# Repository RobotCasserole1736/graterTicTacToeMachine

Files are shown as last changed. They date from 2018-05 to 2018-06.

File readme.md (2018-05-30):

# Tic Tac Toe

This is code for our machine which plays tic tac toe.

It is cheesey. But also grate. Hopefully the kids will love it.

# Gameplay

To begin, the human draws a red X on their board. They place the board into the machine, then press the "Play" button.

The robot analyzes the board state, chooses where to place an O, and draws it. The human takes the board and draws another X. 

The process repeats until one player has won the game.

# Algorithm

A medium-difficulty algorithm has been implemented:
 - If the robot (O's) can win with a single move, the robot will make that move
 - If the human (X's) can win with a single move, the robot will block that move
 - Otherwise, the robot will place in a random location.

# Structure

## JeVois Vision Camera

 - Takes images of the board to determine which spaces are populated by the robot or the human
 - Recieves command from the Arduino to process the present image
 - Transmits board state to the Arduino
 
 ## Arduino
 
  - Mega 
  - Maintains state machine for full robot state
  - On Play button press, sends command to JeVois to read board state
  - Listens for and Parses JeVois response
  - Calculates mark placement location
  - Plans stepper motor paths to draw the mark 
  - Sends commands to stepper motor driver to execute draw
  
  ## Physical Motor
   
   - 3 axis pen moving rig
   
  # Credits
  
  Some days you eat the cheese, some days the cheese eats you.

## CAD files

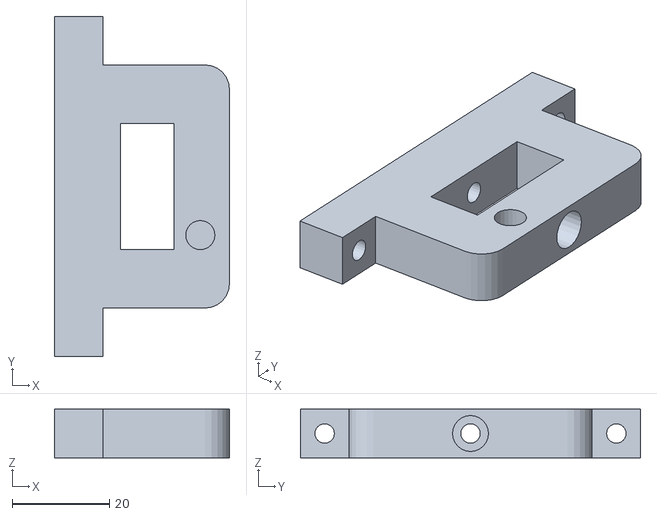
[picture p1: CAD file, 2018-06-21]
3D_Parts/StepperFot.stl
36.0 x 70.0 x 10.0

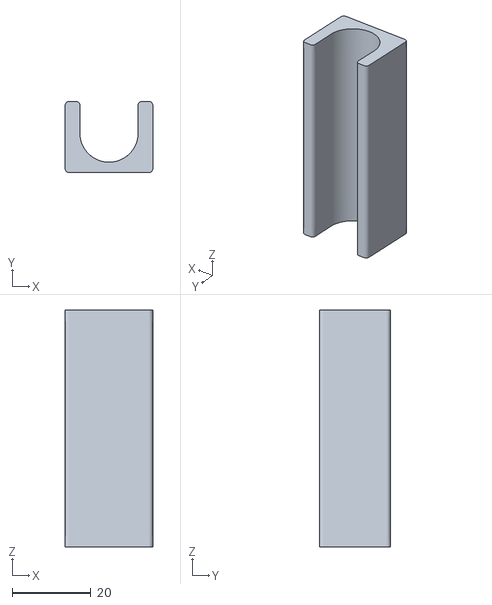
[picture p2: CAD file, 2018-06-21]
3D_Parts/NutStabilizer.stl
22.2 x 18.0 x 60.0

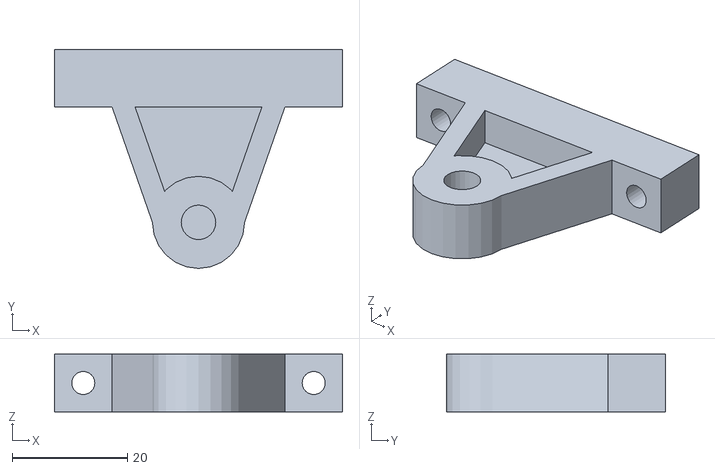
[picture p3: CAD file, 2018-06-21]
3D_Parts/Fot.stl
50.0 x 38.0 x 10.0

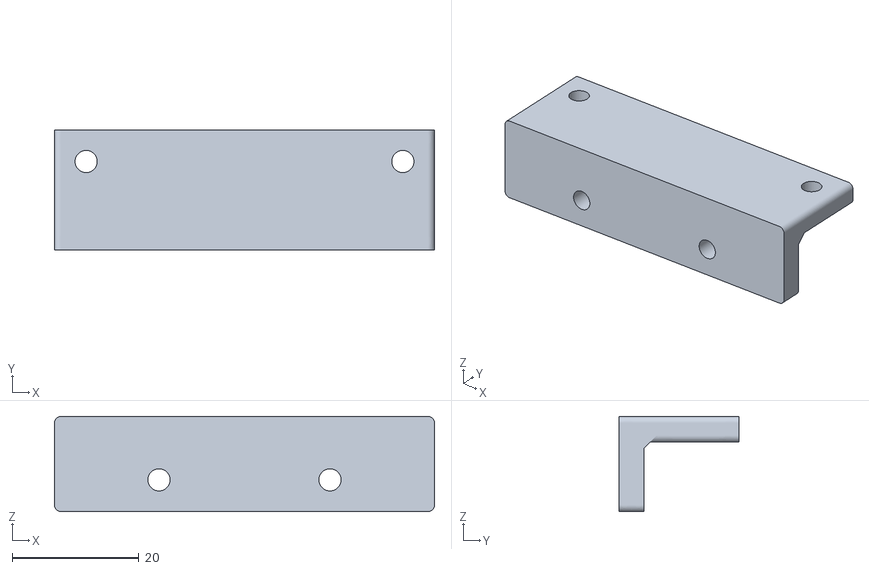
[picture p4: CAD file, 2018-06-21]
3D_Parts/PenStepperMount.stl
60.0 x 19.0 x 15.0

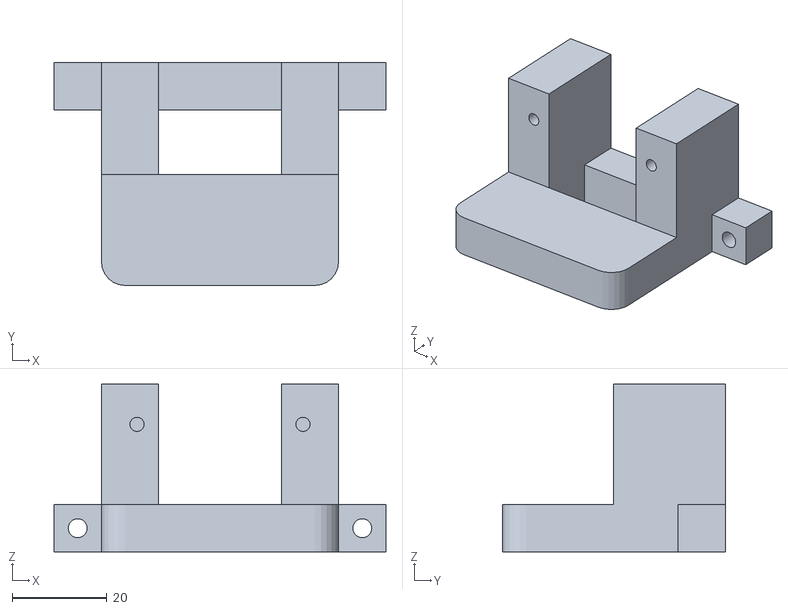
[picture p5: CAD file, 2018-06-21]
3D_Parts/StepperMountY.stl
70.0 x 47.0 x 35.4

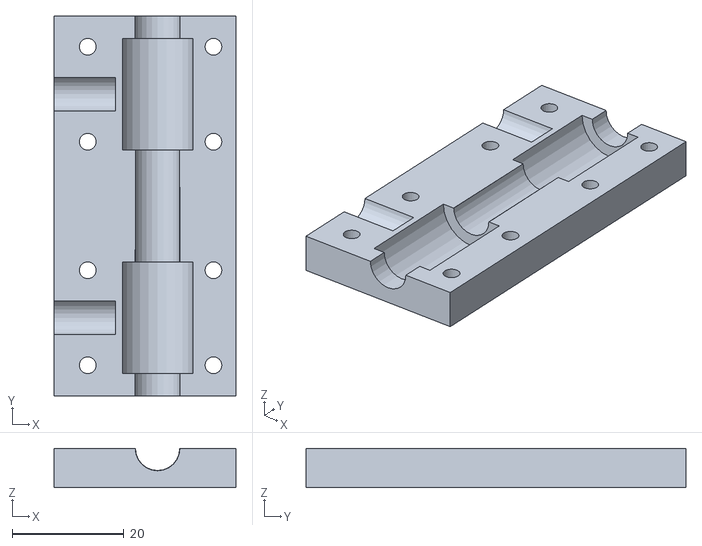
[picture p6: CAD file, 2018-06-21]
3D_Parts/Klammer.stl
32.5 x 68.0 x 7.00

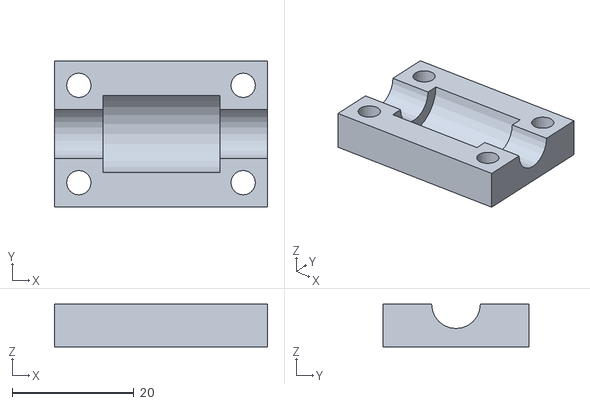
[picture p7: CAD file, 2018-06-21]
3D_Parts/XbaseTop.stl
35.0 x 24.0 x 7.00

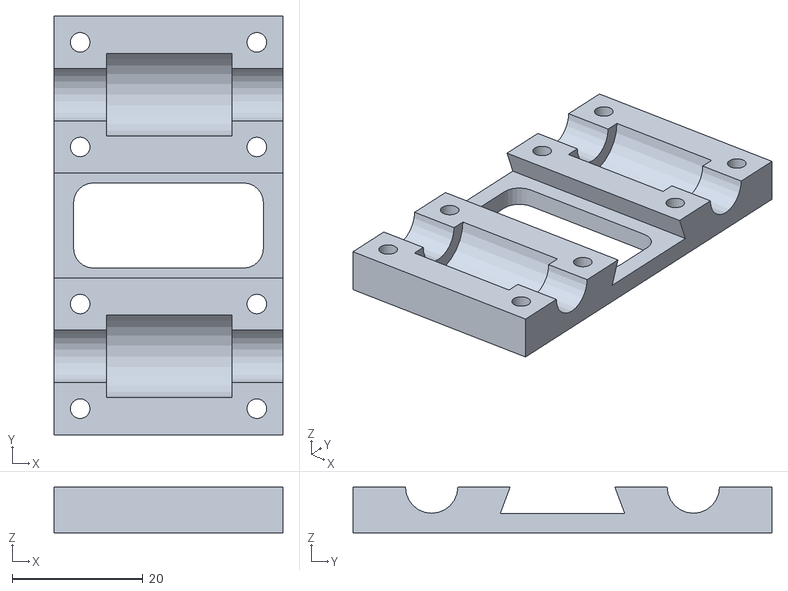
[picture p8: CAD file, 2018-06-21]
3D_Parts/Xbase.stl
35.0 x 64.0 x 7.00

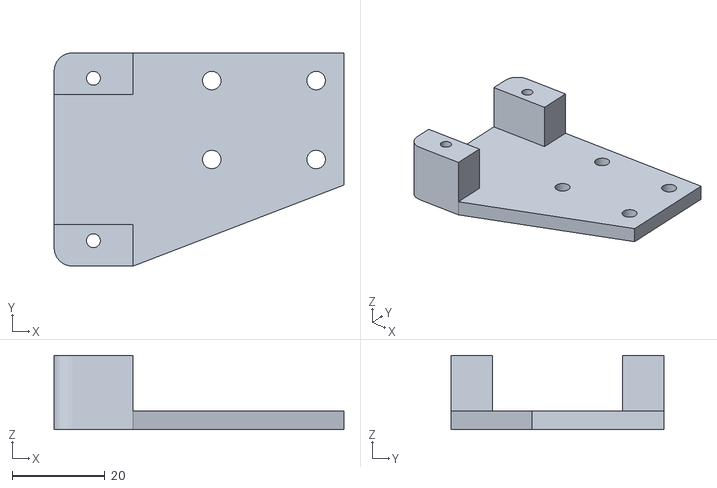
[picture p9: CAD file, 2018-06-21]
3D_Parts/StepperMountX.stl
62.5 x 46.0 x 16.0

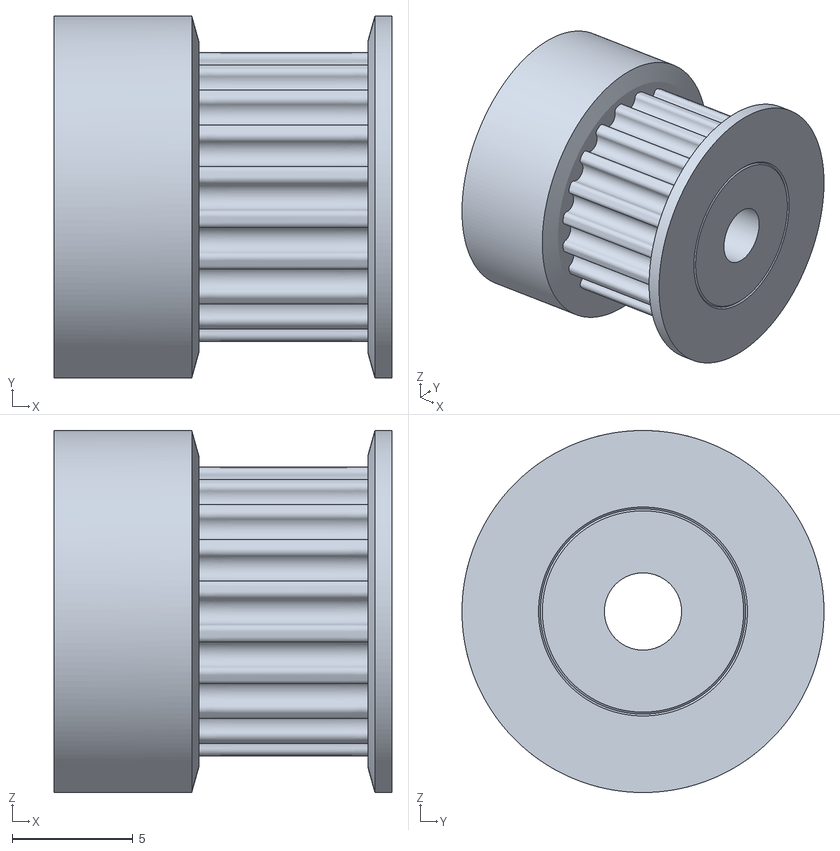
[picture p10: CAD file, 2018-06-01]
3D_Parts/Pulley_GT2.stl
14.0 x 15.0 x 15.0

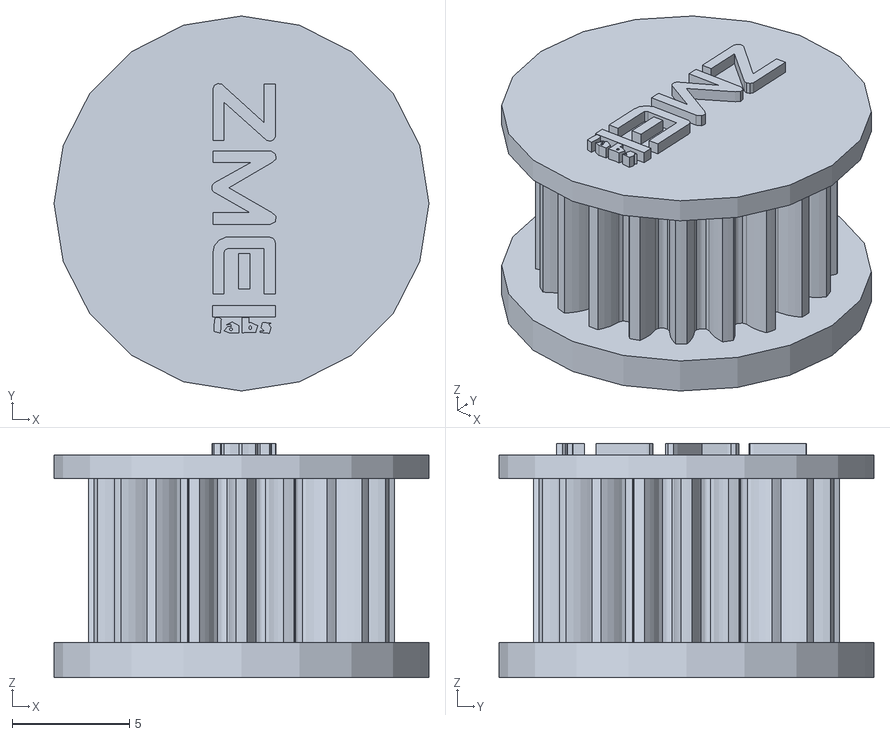
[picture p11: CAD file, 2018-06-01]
3D_Parts/Gears_For_GT02_Arduino.stl
16.0 x 16.0 x 10.0

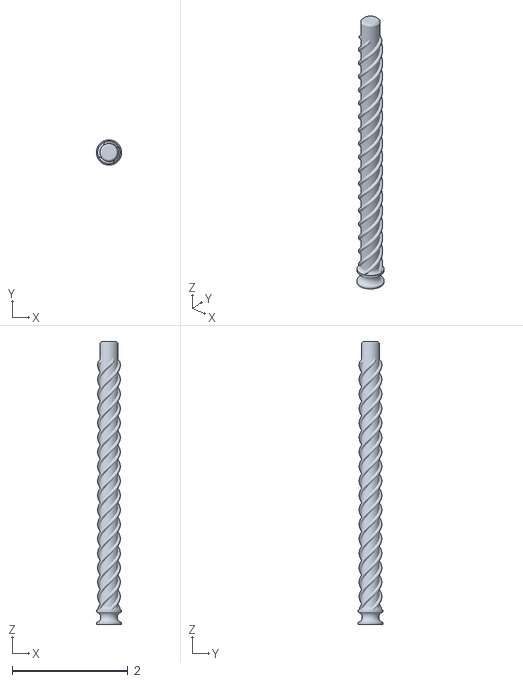
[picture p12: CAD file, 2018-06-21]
3D_Parts/BS-V1-SCREW-1-QUAD.stl
0.437 x 0.437 x 4.89

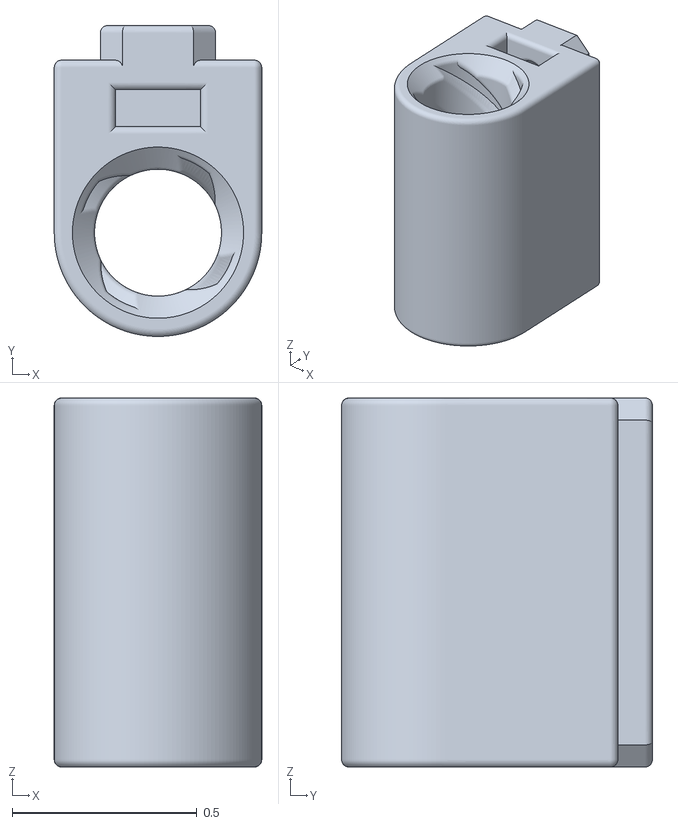
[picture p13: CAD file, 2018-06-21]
3D_Parts/BS-V1-NUT-1.stl
0.563 x 0.843 x 1.00

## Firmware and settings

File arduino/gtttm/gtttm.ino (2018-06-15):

#include "AccelStepper.h"

/*
 * The Grater Tic Tac Toe Machine
 * Plays tic tac toe and such.
 * It's Cheesy and Grate. mmmmmm
 * 
 *          _--"-.
      .-"      "-.
     |""--..      '-.
     |      ""--..   '-.
     |.-. .-".    ""--..".
     |'./  -_'  .-.      |
     |      .-. '.-'   .-'
     '--..  '.'    .-  -.
          ""--..   '_'   :
                ""--..   |
                      ""-' 
 * 
 * Serial
 * See License.txt in the root of the repo!
 */

////////////////////////////////////////////////////////////
// Debug print switches
////////////////////////////////////////////////////////////
//Uncomment this to get a bunch more spammed to the debug serial port
//#define DEBUG_POS


////////////////////////////////////////////////////////////
// Constant Values
////////////////////////////////////////////////////////////

//Physical hardware IO def's
#define X_STEPPER_PIN_1 3
#define X_STEPPER_PIN_2 4
#define X_STEPPER_PIN_3 5
#define X_STEPPER_PIN_4 6

#define Y_STEPPER_PIN_1 7
#define Y_STEPPER_PIN_2 8
#define Y_STEPPER_PIN_3 9
#define Y_STEPPER_PIN_4 10

#define Z_STEPPER_PIN_1 11
#define Z_STEPPER_PIN_2 12
#define Z_STEPPER_PIN_3 16
#define Z_STEPPER_PIN_4 14

//Stepper Operational mode defs
#define HALFSTEP 8

//Jevois interaface
#define JEVOIS_BOARD_STATE_REQ_STR "GRATERTTT\n"
#define JEVOIS_READ_TIMEOUT_MS 10000

//Other IO
#define PLAY_BUTTON_PIN 15
#define PLAY_BUTTON_DBNC_LOOPS 10 //Count to debounce the play button switch for
#define PLAY_BUTTON_PRESSED true //state that digitalRead should return when pressed
#define BUILT_IN_LED_PIN 13


//Motor Motion Constants.
// With the exception of steps/mm, all distances in mm
#define STEPS_PER_MM 60
#define GRID_X_OFFSET 50.0
#define GRID_Y_OFFSET 50.0

#define PEN_UP_POS 0.0
#define PEN_DOWN_POS -50.0
#define CELL_X_SIZE 10.0
#define CELL_Y_SIZE 10.0

#define DRAWN_CIRCLE_RADIUS CELL_X_SIZE/3.0
#define DRAWN_CIRCLE_APROX_STEPS 16 //Number of steps to use to approximate a circle with straight lines

#define MAX_SPEED_MM_PER_SEC 12
#define MAX_ACCEL_MM_PER_SEC2 100

//#define MAX_SPEED_MM_PER_SEC 5000
//#define MAX_ACCEL_MM_PER_SEC2 5000



//Operation states
enum opState_t{
  WAIT_FOR_USER,        //waiting for the user to hit the button to request a move
  REQ_BOARD_STATE,      //Request the board state from the Jevois
  WAIT_FOR_BOARD_STATE, //Wait for the Jevois to return the board state
  CALC_MOVE,            //Calculate which cell to put a mark in
  WAIT_FOR_MOVE         //Make the move,slick
};


////////////////////////////////////////////////////////////
// Global Vars
////////////////////////////////////////////////////////////

//The board is a 3x3 array of cells
// Each cell can be blank (_), have Robot mark (O), or a human mark (X)
// This will be populated by the JeVois's serial response.
//
// Board Numbering & Orientation Scheme:
//              |       |              Positive Z: Down into the paper
//          0   |   1   |   2          
//       _______|_______|_______       |
//              |       |             -+---> X
//          3   |   4   |   5          |
//       _______|_______|_______       |
//              |       |              V
//          6   |   7   |   8          y
//              |       |              
char BoardState[9];

//The present state of the arduino controller
opState_t State;

//Stepper Motor Objects
//Note pins 2/3 are flipped for reasons (????)
//The electrical hookup should match the macro definitions
AccelStepper stepperX(HALFSTEP, X_STEPPER_PIN_1, X_STEPPER_PIN_3, X_STEPPER_PIN_2, X_STEPPER_PIN_4);
AccelStepper stepperY(HALFSTEP, Y_STEPPER_PIN_1, Y_STEPPER_PIN_3, Y_STEPPER_PIN_2, Y_STEPPER_PIN_4);
AccelStepper stepperZ(HALFSTEP, Z_STEPPER_PIN_1, Z_STEPPER_PIN_3, Z_STEPPER_PIN_2, Z_STEPPER_PIN_4);

//Play button debouncing
unsigned int playButtonDbncCounter = PLAY_BUTTON_DBNC_LOOPS;



////////////////////////////////////////////////////////////
// Movement Sequencer - Circle draw algorithm
////////////////////////////////////////////////////////////
#define CELL_UNDEFINED -1
int targetCell = CELL_UNDEFINED;

//In our sequencer, we move through a sequence of steps.
// 0 = move from home to first point of circle
// 1 = Lower pen
// 2 = move first point of circle to second point of circle
// ...
// DRAWN_CIRCLE_APROX_STEPS + 2 = move to final point on circle
// DRAWN_CIRCLE_APROX_STEPS + 3 = Raise pen
// DRAWN_CIRCLE_APROX_STEPS + 4 = move home
unsigned int sequenceStep = 0;

//home->circle, lower pen, draw circle, raise pen, circle->home
#define TOTAL_STEPS  (1 + 1 + DRAWN_CIRCLE_APROX_STEPS + 1 + 1)

//True if we're moving, false if we're done moving
bool moveInProcess = false;
bool newStep = false;

//"Origin" of the target cell - top-right corner
float tgtCellXPos = 0;
float tgtCellYPos = 0;

//Center of the target cell
float tgtCellXCenter = 0;
float tgtCellYCenter = 0;

//Circle points
float circleXCoords[DRAWN_CIRCLE_APROX_STEPS+1] = {0};
float circleYCoords[DRAWN_CIRCLE_APROX_STEPS+1] = {0};

//Sets a new target cell to draw an output in
//Calculates path constants while it's at it.
void mvSeqSetTargetCell(int tgt_in){
  targetCell = tgt_in;

  //Calc the origin of the target cell
  tgtCellXPos = GRID_X_OFFSET + (CELL_X_SIZE * (float)(tgt_in % 3));
  tgtCellYPos = GRID_Y_OFFSET + (CELL_Y_SIZE * (float)(tgt_in / 3));
  
  //calc the center of the cell
  tgtCellXCenter = tgtCellXPos + CELL_X_SIZE/2.0;
  tgtCellYCenter = tgtCellYPos + CELL_Y_SIZE/2.0;

  //Calc the points on the circle
  for(int pointIdx = 0; pointIdx < DRAWN_CIRCLE_APROX_STEPS+1;  pointIdx++){
    float angleRad = ((float)(pointIdx)) / ((float)DRAWN_CIRCLE_APROX_STEPS) * 2.0 * 3.14159;
    circleXCoords[pointIdx] = tgtCellXCenter + DRAWN_CIRCLE_RADIUS * sin( angleRad );
    circleYCoords[pointIdx] = tgtCellYCenter + DRAWN_CIRCLE_RADIUS * cos( angleRad );
  }

  moveInProcess = true;
  sequenceStep = 0;
  newStep = true;

  Serial.println("Finished calculating new path.");
}


unsigned int updateCtr = 0;

void mvSeqUpdate(){
  //Circle-draw algorithm
  if(newStep == true){
     Serial.print("Running step ");
     Serial.print(sequenceStep);
     Serial.println("...");

    if(sequenceStep == 0){
      //Move to start of circle
      stepperX.moveTo(mmToSteps(circleXCoords[0]));
      stepperY.moveTo(mmToSteps(circleYCoords[0]));
      stepperZ.moveTo(mmToSteps(PEN_UP_POS));
    } else if(sequenceStep == 1){
      //Lower pen
      stepperX.moveTo(mmToSteps(circleXCoords[0]));
      stepperY.moveTo(mmToSteps(circleYCoords[0]));
      stepperZ.moveTo(mmToSteps(PEN_DOWN_POS));
    } else if(sequenceStep >= 2 && sequenceStep <= DRAWN_CIRCLE_APROX_STEPS + 2){
      //Draw circle
      stepperX.moveTo(mmToSteps(circleXCoords[sequenceStep-2]));
      stepperY.moveTo(mmToSteps(circleYCoords[sequenceStep-2]));
      stepperZ.moveTo(mmToSteps(PEN_DOWN_POS));
    } else if(sequenceStep == DRAWN_CIRCLE_APROX_STEPS + 3){
      //Raise pen
      stepperX.moveTo(mmToSteps(circleXCoords[DRAWN_CIRCLE_APROX_STEPS]));
      stepperY.moveTo(mmToSteps(circleYCoords[DRAWN_CIRCLE_APROX_STEPS]));
      stepperZ.moveTo(mmToSteps(PEN_UP_POS));
    }else if(sequenceStep == DRAWN_CIRCLE_APROX_STEPS + 4){
      //Move home
      stepperX.moveTo(mmToSteps(0));
      stepperY.moveTo(mmToSteps(0));
      stepperZ.moveTo(mmToSteps(PEN_UP_POS));
    } else {
      //IDK let's go home
      stepperX.moveTo(mmToSteps(0));
      stepperY.moveTo(mmToSteps(0));
      stepperZ.moveTo(mmToSteps(PEN_UP_POS));
    }
  }

  //If we're at 0 distance-to-go, we can move on to the next step
  if(stepperX.isRunning() == false &&
     stepperY.isRunning() == false &&
     stepperZ.isRunning() == false ) {

       sequenceStep++;
       newStep = true;
       moveInProcess = true;

       Serial.print("Finished step ");
       Serial.println(sequenceStep-1);
       if( sequenceStep > TOTAL_STEPS){
         //All done, clean up variable state
         moveInProcess = false;
         newStep = false;
         sequenceStep = 0;
       }
       
  } else {
    newStep = false;
    moveInProcess = true;
    
  #ifdef DEBUG_POS
    Serial.println("\n\n===============");
    Serial.print("POS X = ");
    Serial.println(stepperX.currentPosition());
    Serial.print("POS Y = ");
    Serial.println(stepperY.currentPosition());
    Serial.print("POS Z = ");
    Serial.println(stepperZ.currentPosition());
  #endif
  }

}

void mvSeqOutputUpdate(){
  //Do periodic output updates
  stepperX.run();
  stepperY.run();
  stepperZ.run();
}



////////////////////////////////////////////////////////////
// Utility functions
////////////////////////////////////////////////////////////
void resetState(){
  State = WAIT_FOR_USER;
  for(int cellIdx = 0; cellIdx < 9; cellIdx++){
    BoardState[cellIdx] = "_";
  }

  targetCell = CELL_UNDEFINED;
}

//Returns an index 0-8 to say where the robot should place a 
// mark. Should calculate this based on BoardState.
int moveCalculator(){
  int des_move = 0;
  int avail_cells[9] = {0};
  int num_avail_cells = 0;

  //Populate the array of available moves
  for(int cell = 0; cell < 9; cell++){
    if(BoardState[cell] == ' '){
      avail_cells[num_avail_cells++] = cell;
    }
  }

  //Check for no move available
  if(num_avail_cells == 0){
    return -1;
  }
  
  //TODO: Fill me in with logic to win against the kids, but not too hard

  //else: choose randomly
  des_move = avail_cells[random(0,num_avail_cells)];

  return des_move;

}

//converts mm to steps
float mmToSteps(float mm){
  return STEPS_PER_MM * mm;
}

void printBoardState(void){
  Serial.println("Board State:");
  Serial.println("       |     |     ");   
  Serial.print("    ");Serial.print(BoardState[0]);Serial.print("  |  ");Serial.print(BoardState[1]);Serial.print("  |  ");Serial.print(BoardState[2]);Serial.print("  \n");
  Serial.println("       |     |     "); 
  Serial.println("  -----+-----+-----"); 
  Serial.println("       |     |     "); 
  Serial.print("    ");Serial.print(BoardState[3]);Serial.print("  |  ");Serial.print(BoardState[4]);Serial.print("  |  ");Serial.print(BoardState[5]);Serial.print("  \n");
  Serial.println("       |     |     "); 
  Serial.println("  -----+-----+-----"); 
  Serial.println("       |     |     "); 
  Serial.print("    ");Serial.print(BoardState[6]);Serial.print("  |  ");Serial.print(BoardState[7]);Serial.print("  |  ");Serial.print(BoardState[8]);Serial.print("  \n");
  Serial.println("       |     |     "); 
}




////////////////////////////////////////////////////////////
// Main Arduino Functions
////////////////////////////////////////////////////////////

void setup() {

  //Serial setup
  Serial.begin(115200); //Debug & command serial port

  Serial.println("+++++++++++++++++++++++++++++++++++++++");
  Serial.println("+++  WELCOME TO GRATER TIC TAC TOE  +++");
  Serial.println("+++++++++++++++++++++++++++++++++++++++");

  //Init Globals
  resetState();

  //configure Pins
  pinMode(PLAY_BUTTON_PIN, INPUT);
  pinMode(BUILT_IN_LED_PIN, OUTPUT);

  //Configure Stepper motors
  stepperX.setMaxSpeed(mmToSteps(MAX_SPEED_MM_PER_SEC));
  stepperX.setAcceleration(mmToSteps(MAX_ACCEL_MM_PER_SEC2));

  stepperY.setMaxSpeed(mmToSteps(MAX_SPEED_MM_PER_SEC));
  stepperY.setAcceleration(mmToSteps(MAX_ACCEL_MM_PER_SEC2));

  stepperZ.setMaxSpeed(mmToSteps(MAX_SPEED_MM_PER_SEC));
  stepperZ.setAcceleration(mmToSteps(MAX_ACCEL_MM_PER_SEC2));

  Serial.println("Finished Init");
}

void loop() {
  bool boardStateRXed = false;
  
  //Main state machine
  opState_t prevState = State;

  //handle in-state logic
  switch(State){
    case WAIT_FOR_USER:
      //Debounce the play button
     // if(digitalRead(PLAY_BUTTON_PIN) == PLAY_BUTTON_PRESSED){
       // if(playButtonDbncCounter != 0){
        //  playButtonDbncCounter--;
       // }
      //} else {
        playButtonDbncCounter = PLAY_BUTTON_DBNC_LOOPS;
      //}

      //debug
      if(Serial.read() == 'g'){
        playButtonDbncCounter = 0;
      }

      //Flush the jevois serial port
      while(Serial.available() != 0){
        Serial.read(); //Discard remaining buffer contents
      }

    break;

    case REQ_BOARD_STATE:
      //Send command to JeVois
      Serial.write(JEVOIS_BOARD_STATE_REQ_STR);
    break;

    case WAIT_FOR_BOARD_STATE:
      if(Serial.read() == '^'){
        while(Serial.available() < 9){};
        for(int cellIdx = 0; cellIdx < 9; cellIdx++){
          BoardState[cellIdx] = Serial.read();
          
        }
        boardStateRXed = true;
        while(Serial.available() != 0){
          Serial.read(); //Discard remaining buffer contents
        }
      }
    break;

    case CALC_MOVE:
      mvSeqSetTargetCell(moveCalculator());
    break;

    case WAIT_FOR_MOVE:
      mvSeqUpdate();
    break;

    default:

    break;
  }



  //Calc new state
  switch(State){
    case WAIT_FOR_USER:
      if(playButtonDbncCounter == 0){
        Serial.println("Requesting board state from Jevois...");
        State = REQ_BOARD_STATE;
      } else {
        State = WAIT_FOR_USER;
      }
    break;

    case REQ_BOARD_STATE:
      State = WAIT_FOR_BOARD_STATE;
    break;

    case WAIT_FOR_BOARD_STATE:
      if(boardStateRXed){
        Serial.println("Got board state, calculating move...");
        printBoardState();
        State = CALC_MOVE;
      } else {
        State = WAIT_FOR_BOARD_STATE;
      }
    break;

    case CALC_MOVE:
      Serial.println("Performing move...");
      State = WAIT_FOR_MOVE;
    break;

    case WAIT_FOR_MOVE:
      if(moveInProcess == false){
        Serial.println("Move complete! Waiting for user input...");
        State = WAIT_FOR_USER;
      } else {
        State = WAIT_FOR_MOVE;
      }
    break;

    default:
      State = WAIT_FOR_USER; //if all else fails, go back to the init state
    break;
  }


  mvSeqOutputUpdate();

}

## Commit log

2018-05-23 - Adding a few initial parts
    [Gears_For_GT02_Arduino.stl, Pulley_GT2.stl, RodHolder.stl]
2018-06-01 Added license, and minor tweak in comments to arduino code
2018-06-13 Added a quick test, tweaked stepper hookups and settings to match happy settings
2018-06-21 - Updated 3D parts to all parts currently being used. Still waiting on real smooth rod and bearings so some changes may still be made.
    [BS-V1-NUT-1.stl, BS-V1-SCREW-1-QUAD.stl, Fot.stl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]
